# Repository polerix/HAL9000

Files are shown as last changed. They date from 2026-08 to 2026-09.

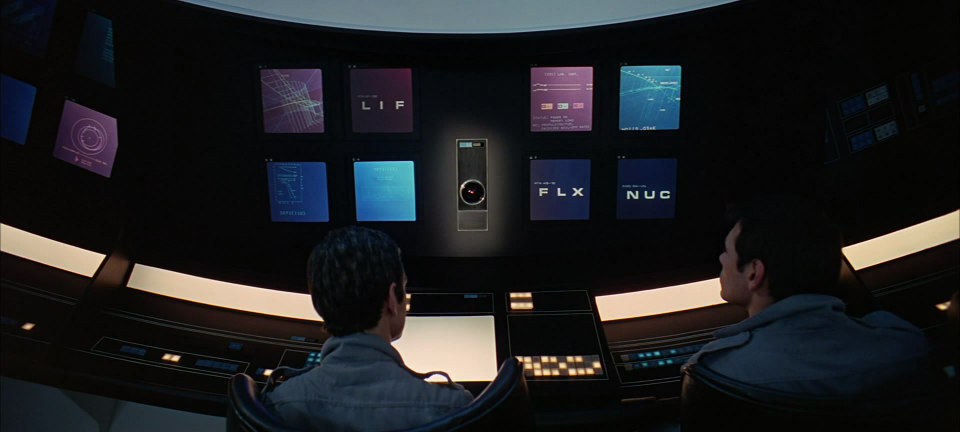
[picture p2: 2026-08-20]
Images/HAL9000_Resources/hal-2001.jpg

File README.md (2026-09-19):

# HAL 9000 Viewscreen

Life-size HAL 9000 replica display system. A Pygame kiosk app drives a 7" 1024×600 HDMI display in portrait orientation (600×1024), cycling through 12 spacecraft systems every 30 seconds and showing two panels per system:

- **High Screen** – Red function label panel with the active system code (e.g. `ATM`, `NAV`, `DMG`)
- **Lower Screen** – Looping video animation matching the current function

Primary deployment target is a Raspberry Pi 3 driving the physical prop display — see [`RaspberryPi 3.md`](RaspberryPi%203.md) for hardware wiring, HDMI/portrait config, and the systemd service. This README covers running and developing the app, including on a desktop (macOS/Linux) for testing.

## Requirements

- Python 3.10+
- [`pygame-ce`](https://pyga.me/) (community fork of pygame — see note below)

Dependencies are pinned in [`requirements.txt`](requirements.txt).

> **Why pygame-ce, not pygame:** `pygame` 2.6.1 has a circular-import bug in `pygame.font` on newer Python releases (confirmed on 3.14), which crashes the app on startup with `NotImplementedError: font module not available`. `pygame-ce` is an actively maintained, drop-in-compatible fork without that bug. If you're on an older/stable Python and prefer upstream `pygame`, it should still work — just swap the pin in `requirements.txt`.

## Quick Start (Desktop / macOS testing)

Use a virtual environment so nothing touches your system Python:

```bash
cd HAL9000
python3 -m venv .venv
source .venv/bin/activate
pip install -r requirements.txt

python3 hal_viewscreen.py --windowed   # windowed, for testing
python3 hal_viewscreen.py              # fullscreen
```

`.venv/` is self-ignored by git (venvs created with `python -m venv` write their own `.gitignore`), so it never needs to be committed.

## Quick Start (Raspberry Pi 3, production)

```bash
git clone <repo-url> ~/HAL9000
cd ~/HAL9000
chmod +x setup_pi.sh
sudo ./setup_pi.sh
sudo reboot
```

Full hardware setup, HDMI portrait config, and systemd service management: see [`RaspberryPi 3.md`](RaspberryPi%203.md).

## Keyboard Controls (Testing)

| Key | Action |
|---|---|
| `→` Right Arrow | Next function |
| `←` Left Arrow | Previous function |
| `Space` | Resume auto-cycling |
| `Esc` | Quit |

## System Functions

| Code | System | Subtitle |
|---|---|---|
| ATM | Spacecraft Atmosphere Monitoring | O2N: 14-RA |
| CNT | Control | SYS: 09-MX |
| COM | Communications | FRQ: 31-AE |
| DMG | System Damage | GPM: 72-KC |
| FLX | Flight Dynamics | DYN: 58-PL |
| GDE | Guidance Data Extension | NAV: 43-QR |
| HIB | Hibernation | CRY: 06-TB |
| LIF | Life Support | ENV: 21-SG |
| MEM | Memory | BNK: 88-FH |
| NAV | Navigation | TRJ: 55-WD |
| NUC | Nuclear Reactor Status | RCT: 37-JN |
| VEH | Vehicle Status | HUL: 64-BV |

## Architecture

```
hal_viewscreen.py      Main application (Pygame)
├── config.py          Constants, layout, function definitions
├── Video/             MP4 animations (7-8 per function)
├── Fonts/             Eurostile KFB font family
└── Artwork/SVG/       Screen layout + example panel
```

## Files

| File | Purpose |
|---|---|
| `hal_viewscreen.py` | Main display application |
| `config.py` | Configuration & constants |
| `requirements.txt` | Python dependencies |
| `setup_pi.sh` | Raspberry Pi setup script |
| `hal9000-viewscreen.service` | Systemd auto-start unit (Pi) |
| `RaspberryPi 3.md` | Hardware setup & Pi deployment reference |
| `7" ScreenSpecifications.md` | Display hardware spec sheet |

## Notes

- Video playback is fully in-window: frames are decoded with OpenCV and drawn directly onto the same pygame surface as the rest of the UI, rather than shelling out to an external player. There is no separate OS-level video window to position — the whole display is one window.
- This is software decoding. See [`RaspberryPi 3.md`](RaspberryPi%203.md) for a note on Pi 3 performance if you deploy there.
- The `set_function()` API in `FunctionController` is ready for external control (Arduino serial, network, etc.)
- Cycle interval is configurable in `config.py` (`CYCLE_INTERVAL_SEC`)
- Font rendering uses Eurostile KFB Bold Extended (matching the movie prop typography)

## Licensing

The source code in this repository is released under the [MIT License](LICENSE).

Third-party material bundled in this repository (fonts, audio, video, artwork, saved web pages and similar files) is **not** covered by that license. It remains the property of its respective owners and is included under their own terms. If you are a rights holder and want something removed, please open an issue.

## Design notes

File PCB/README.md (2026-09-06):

# HAL 9000 Keypad PCB

10-button backlit keypad for the HAL 9000 terminal. Connects to a Vasiumic MCP23017 I2C GPIO expander via Dupont wires.

## Specs
- Board: 75.10 × 30.20 mm, 2-layer
- Buttons: 6×6×5mm momentary tactile, 4-pin DIP, 15mm pitch (2×5 grid)
- LEDs: 5mm through-hole, always-on, one per button in function color
- Resistors: current-limiting per LED color (330Ω red, 270Ω green, 180Ω blue, 300Ω amber)
- J1: 10-pin 2.54mm Dupont → MCP23017 GPA0–7 + GPB0–1
- J2: 2-pin power (5V + GND)

## Button Layout (row × col)
| | Col 1 | Col 2 | Col 3 | Col 4 | Col 5 |
|---|---|---|---|---|---|
| Row 1 | HIB | LIF | COM | NAV | MEM |
| Row 2 | ATM | FLX | NUC | WEA | MED |

## Files
- `hal9000-keypad/` — KiCad project (.kicad_sch, .kicad_pcb, .kicad_pro)
- `hal9000-keypad-pcb.zip` — full project archive for peer review
- `author-hal9000-keypad.mjs` — MCP authoring script that generated this design

## Notes
Resistors may need manual placement adjustment in KiCad PCB editor to clear courtyard overlaps (all nets and footprints are correct).

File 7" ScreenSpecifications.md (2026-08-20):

Generic 7 Inch 
1024 * 600 
DIY Portable LCD Display Screen Monitor 
Mini-HDMI Driver Control Board PC Computer Secondary Screen
black 
7C GQ -852
PCB80052

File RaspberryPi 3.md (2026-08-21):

# HAL 9000 – Raspberry Pi 3 Viewscreen

## Overview

Life-size HAL 9000 replica display system running on Raspberry Pi 3. Drives a 7" 1024×600 HDMI display in portrait orientation (600×1024), showing two panels:

- **High Screen** – Red function label panel with the active system code (e.g. `ATM`, `NAV`, `DMG`)
- **Lower Screen** – Looping video animation matching the current function

The display cycles through 12 spacecraft systems every 30 seconds, randomly selecting one of 7-8 available animations per system.

## Hardware

| Component | Specification |
|---|---|
| Computer | Raspberry Pi 3 Model B |
| Display | Generic 7" 1024×600 HDMI (PCB80052, 7C GQ-852) |
| Connection | Mini-HDMI to HDMI |
| Orientation | Portrait (600×1024) |

## Quick Start

### 1. Clone to Raspberry Pi
```bash
git clone <repo-url> ~/HAL9000
cd ~/HAL9000
```

### 2. Run Setup
```bash
chmod +x setup_pi.sh
sudo ./setup_pi.sh
sudo reboot
```

### 3. Start Manually (for testing)
```bash
# Windowed mode (on desktop)
python3 hal_viewscreen.py --windowed

# Fullscreen
python3 hal_viewscreen.py
```

### 4. Service Commands
```bash
sudo systemctl start hal9000-viewscreen    # Start
sudo systemctl stop hal9000-viewscreen     # Stop
sudo systemctl status hal9000-viewscreen   # Status
journalctl -u hal9000-viewscreen -f        # Live logs
```

## Keyboard Controls (Testing)

| Key | Action |
|---|---|
| `→` Right Arrow | Next function |
| `←` Left Arrow | Previous function |
| `Space` | Resume auto-cycling |
| `Esc` | Quit |

## System Functions

| Code | System | Subtitle | Panel Color |
|---|---|---|---|
| ATM | Spacecraft Atmosphere Monitoring | MRN: 80-EJ | Crimson Red (`#9D0032`) |
| CNT | Control | VER: 80-KJ | Sage Green (`#426F49`) |
| COM | Communications | PMT: 26-07 | Plum Magenta (`#733863`) |
| DMG | System Damage | GPM: 72-KC | Bright Crimson (`#C10341`) |
| FLX | Flight Dynamics | ATA: 48-12 | Royal Blue (`#294194`) |
| GDE | Guidance Data Extension | LIF: 13-AG | Cerulean Blue (`#2C4DA1`) |
| HIB | Hibernation | STA: 35-05 | Dark Teal (`#074941`) |
| LIF | Life Support | ATA: 61-08 | Rose Magenta (`#9E214B`) |
| MEM | Memory | PMT: 49-XB | Slate Steel Blue (`#17395A`) |
| NAV | Navigation | RTE: 09-EF | Deep Violet (`#52316B`) |
| NUC | Nuclear Reactor Status | AQS: 64-VN | Midnight Navy (`#0F1738`) |
| VEH | Vehicle Status | LIN: 86-QW | Cobalt Blue (`#2C4DA1`) |

## Architecture

```
hal_viewscreen.py      Main application (Pygame)
├── config.py          Constants, layout, function definitions
├── Video/             MP4 animations (7-8 per function)
├── Fonts/             Eurostile KFB font family
└── Artwork/SVG/       Screen layout + example panel
```

### Display Layout (600×1024)

```
┌──────────────────────────┐  0
│          (black)          │
│   ┌──────────────────┐   │  28px
│   │                  │   │
│   │   HIGH SCREEN    │   │
│   │   (red panel)    │   │
│   │   Function Label │   │
│   │                  │   │
│   └──────────────────┘   │  501px
│          (black)          │
│   ┌──────────────────┐   │  523px
│   │                  │   │
│   │   LOWER SCREEN   │   │
│   │   (video area)   │   │
│   │   video playback │   │
│   │                  │   │
│   └──────────────────┘   │  996px
│          (black)          │
└──────────────────────────┘  1024
    64px              537px
```

## Files

| File | Purpose |
|---|---|
| `hal_viewscreen.py` | Main display application |
| `config.py` | Configuration & constants |
| `setup_pi.sh` | Raspberry Pi setup script |
| `hal9000-viewscreen.service` | Systemd auto-start unit |
| `requirements.txt` | Python dependencies |

## Notes

- Videos are 4K source files decoded via OpenCV and drawn directly onto the pygame surface (in-process, same window as the rest of the UI — no separate player window). Frames are resized down to 473×473px each draw call.
- This is software decoding, not hardware-accelerated. On a Pi 3 this may not sustain smooth playback of full 4K source files — if you see dropped frames or high CPU, pre-transcode the videos in `Video/` down to roughly panel resolution (e.g. `ffmpeg -i in.mp4 -vf scale=473:473 out.mp4`) so decode cost matches what's actually displayed.
- The `set_function()` API in `FunctionController` is ready for external control (Arduino serial, network, etc.)
- Cycle interval is configurable in `config.py` (`CYCLE_INTERVAL_SEC`)
- Font rendering uses Eurostile KFB Bold Extended (matching the movie prop typography)

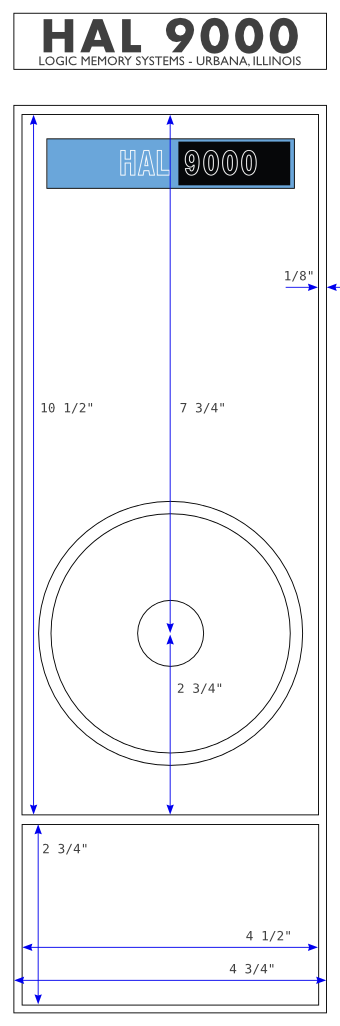
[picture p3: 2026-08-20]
Images/HAL9000_Resources/hal9000-faceplate.png

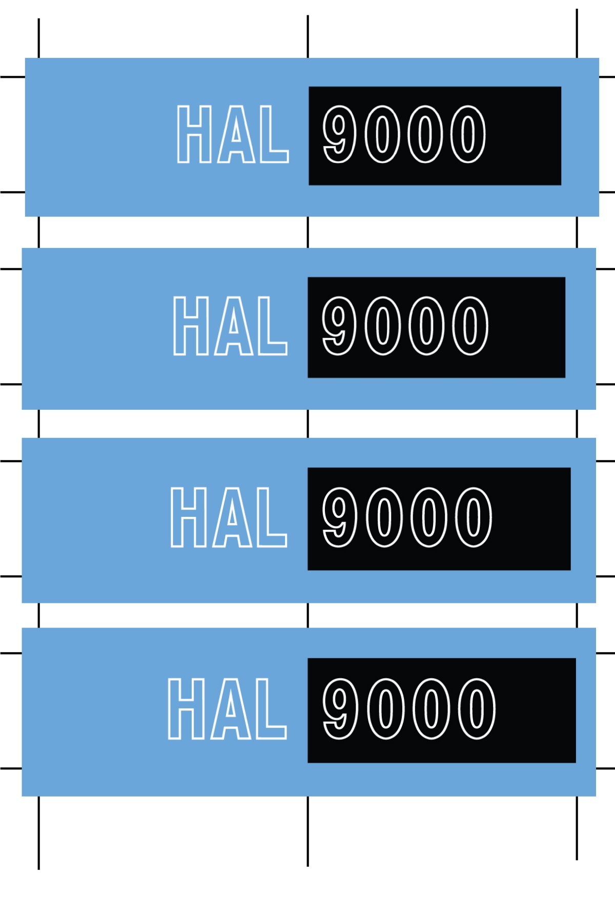
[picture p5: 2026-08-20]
Images/HAL9000_Resources/hal9000-decal.jpg

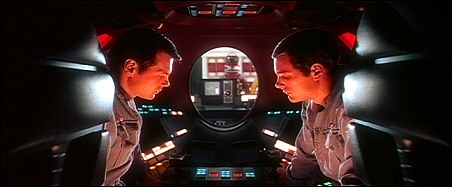
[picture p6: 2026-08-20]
Images/HAL9000_Resources/hal-podbay2.jpg

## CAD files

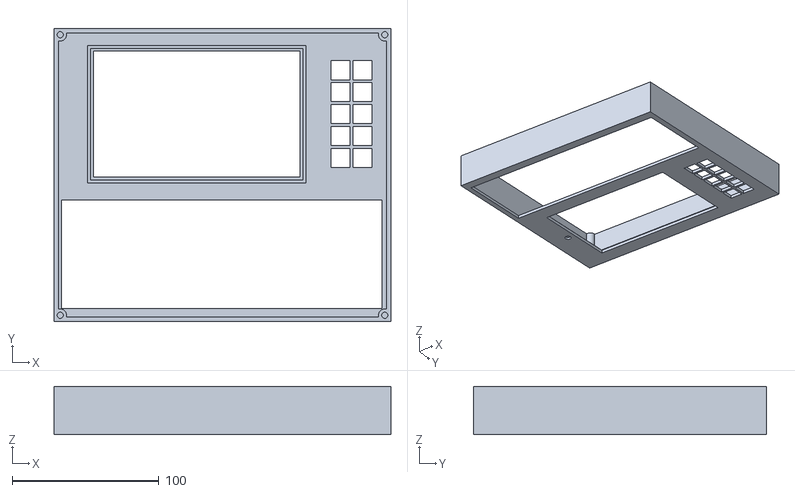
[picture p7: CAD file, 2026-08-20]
Terminal_Parts/Main Body.stl.stl
230.0 x 200.0 x 33.0

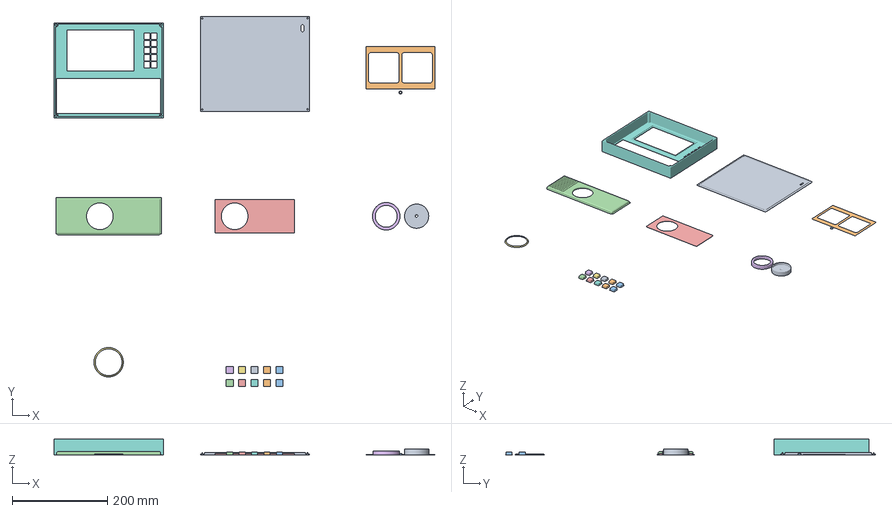
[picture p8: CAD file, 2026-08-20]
hal9000_Terminal.3mf
801.8 x 779.4 x 33.0 mm
Rear Cover.stl
Screen Border.stl
Faux Camera.stl
Silver Iris Panel.stl
Black Iris Panel.stl
Black Iris Border.stl
Silver Iris Ring.stl
Main Body.stl
Rear Lens Cap.stl
CLR Btn.stl
COMM Btn.stl
COMP Btn.stl
EXEC Btn.stl
HIB Btn.stl
LIF Btn.stl
PROG Btn.stl
STP Btn.stl
SYS Btn.stl
VOC Btn.stl

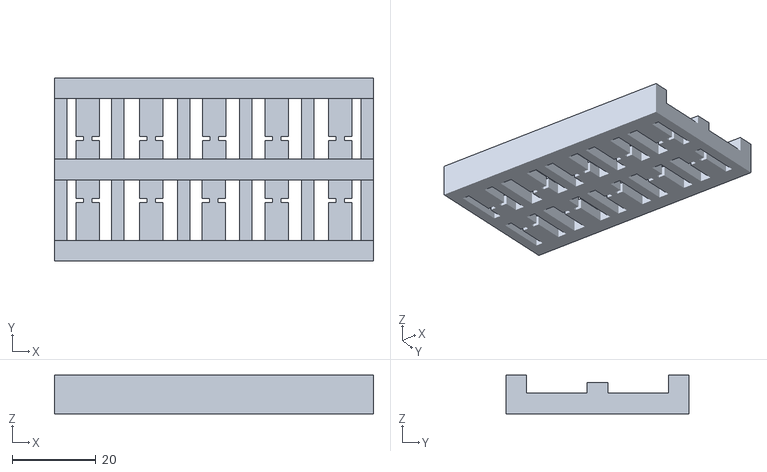
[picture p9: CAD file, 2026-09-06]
Terminal_Parts/Raspberry Pi HAL9000 screen Mask.stl
76.0 x 43.5 x 9.25

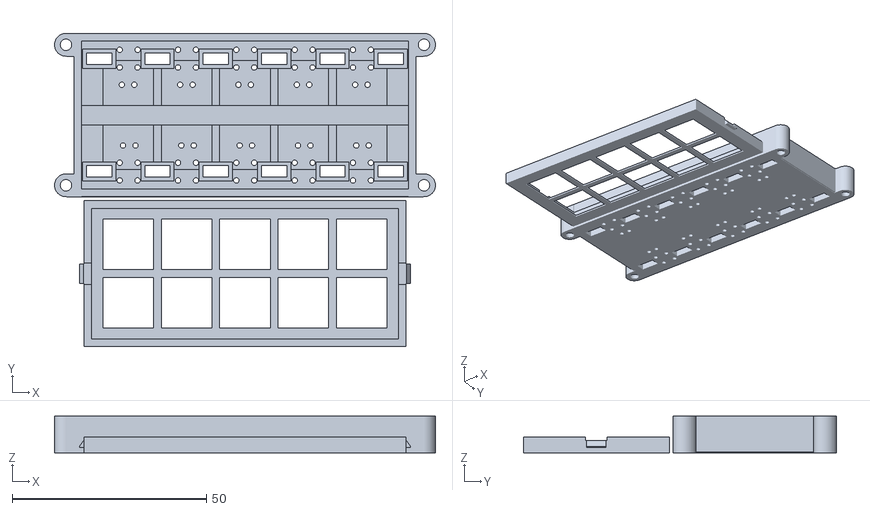
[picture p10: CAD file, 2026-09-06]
Terminal_Parts/Raspberry Pi HAL9000 keypad.stl
98.0 x 80.6 x 9.40

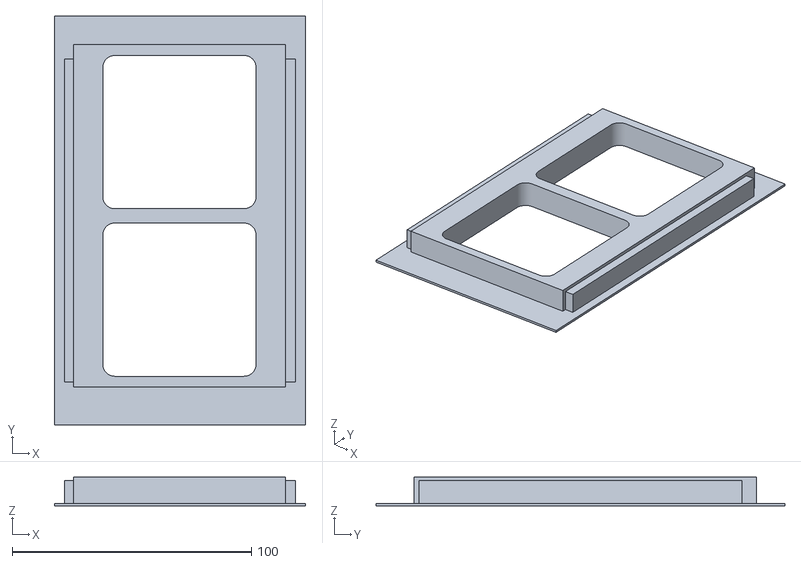
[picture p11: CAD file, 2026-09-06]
Terminal_Parts/Raspberry Pi HAL9000 screen blocker.stl
105.0 x 170.9 x 12.0

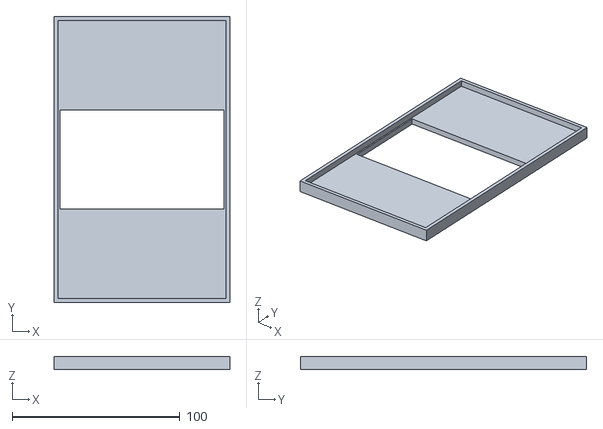
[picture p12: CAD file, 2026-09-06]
Terminal_Parts/Raspberry Pi HAL9000 screen cage.stl
105.0 x 170.9 x 8.00

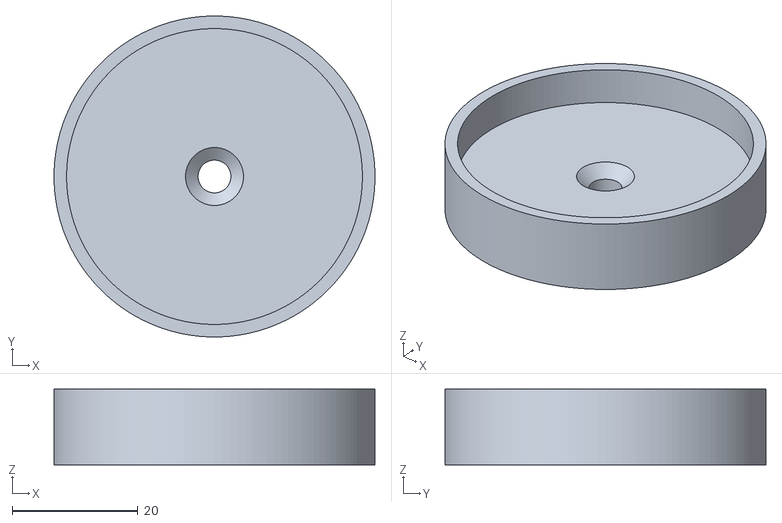
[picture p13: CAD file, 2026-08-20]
Terminal_Parts/Rear Lens Cap.stl.stl
51.0 x 51.0 x 12.0

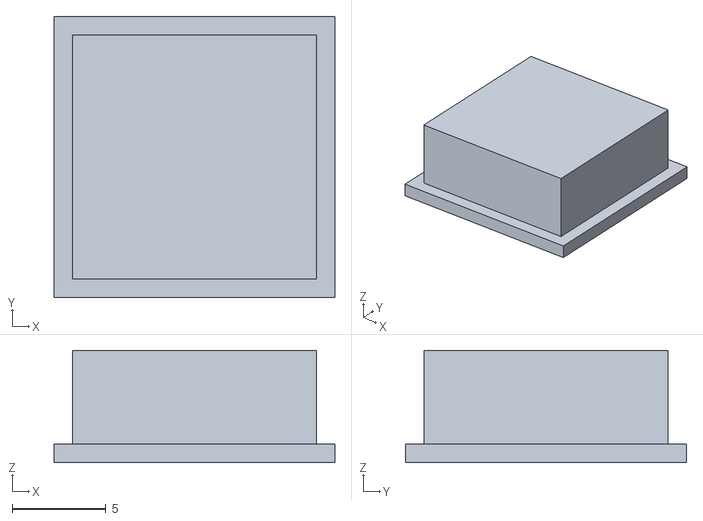
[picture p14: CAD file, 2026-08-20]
Terminal_Parts/SYS Btn.stl.stl
15.0 x 15.0 x 6.00

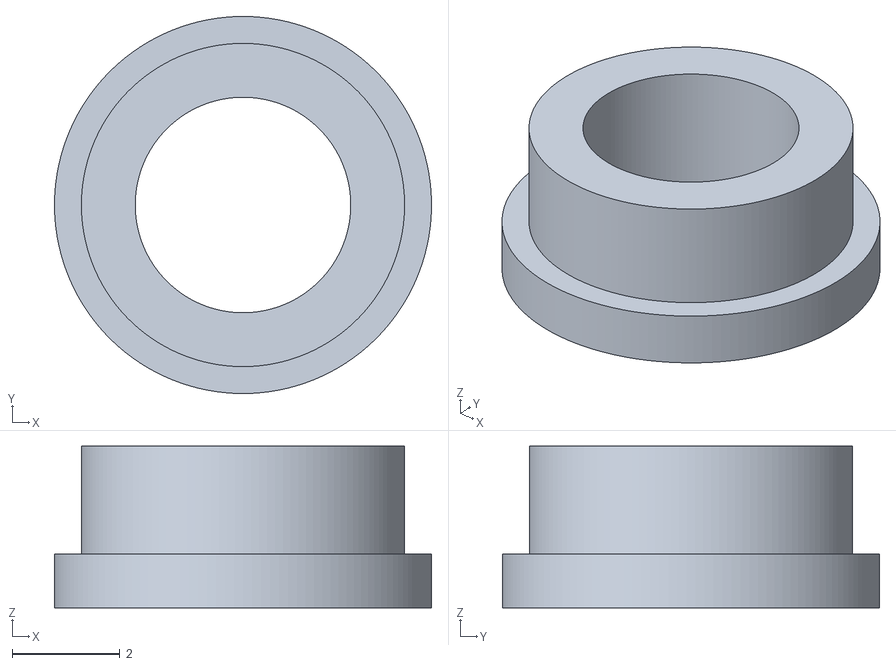
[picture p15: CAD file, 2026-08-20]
Terminal_Parts/Faux Camera.stl.stl
7.00 x 7.00 x 3.00

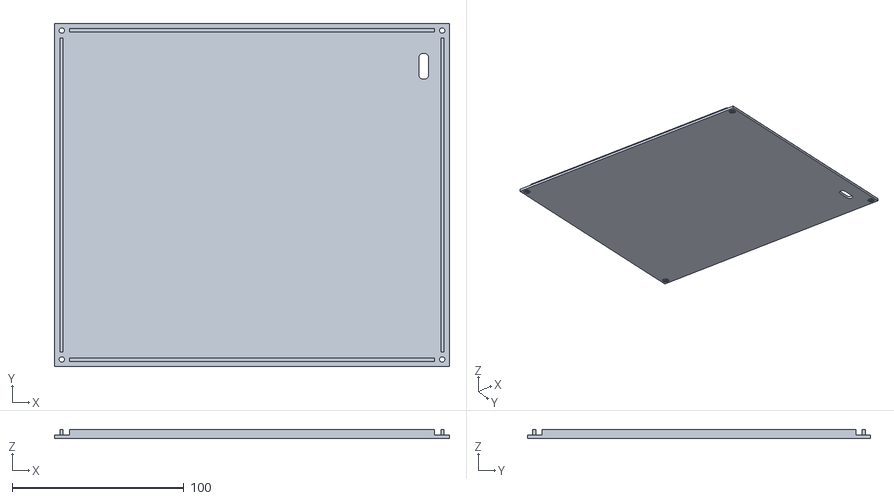
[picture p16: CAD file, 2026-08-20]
Terminal_Parts/Rear Cover.stl.stl
230.0 x 200.0 x 5.00

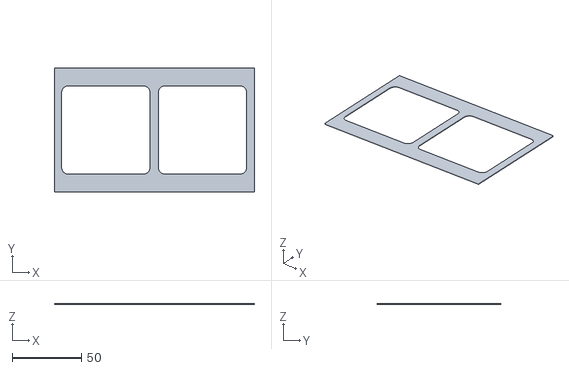
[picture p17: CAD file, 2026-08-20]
Terminal_Parts/Screen Border.stl.stl
144.8 x 89.8 x 1.00

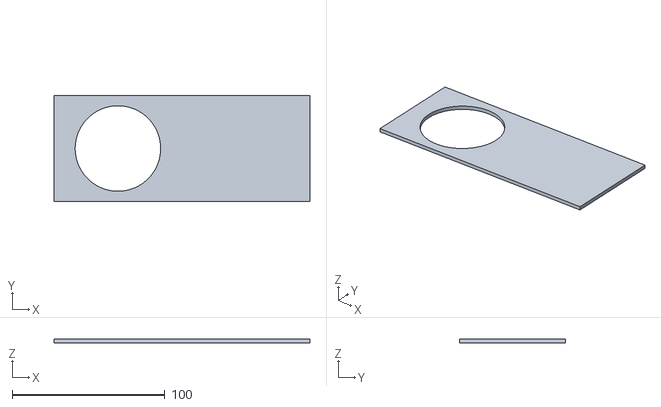
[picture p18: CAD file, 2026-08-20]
Terminal_Parts/Black Iris Panel.stl.stl
167.8 x 69.8 x 2.50

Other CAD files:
Terminal_Parts/PROG Btn.stl.stl
Terminal_Parts/HIB Btn.stl.stl
Terminal_Parts/EXEC Btn.stl.stl
Terminal_Parts/LIF Btn.stl.stl
Terminal_Parts/VOC Btn.stl.stl
Terminal_Parts/COMM Btn.stl.stl
Terminal_Parts/Black Iris Border.stl.stl
Terminal_Parts/CLR Btn.stl.stl
Terminal_Parts/COMP Btn.stl.stl
Terminal_Parts/STP Btn.stl.stl
Terminal_Parts/Silver Iris Panel.stl.stl
Terminal_Parts/Silver Iris Ring.stl.stl
Terminal_Parts/hal9000_Terminal.3mf

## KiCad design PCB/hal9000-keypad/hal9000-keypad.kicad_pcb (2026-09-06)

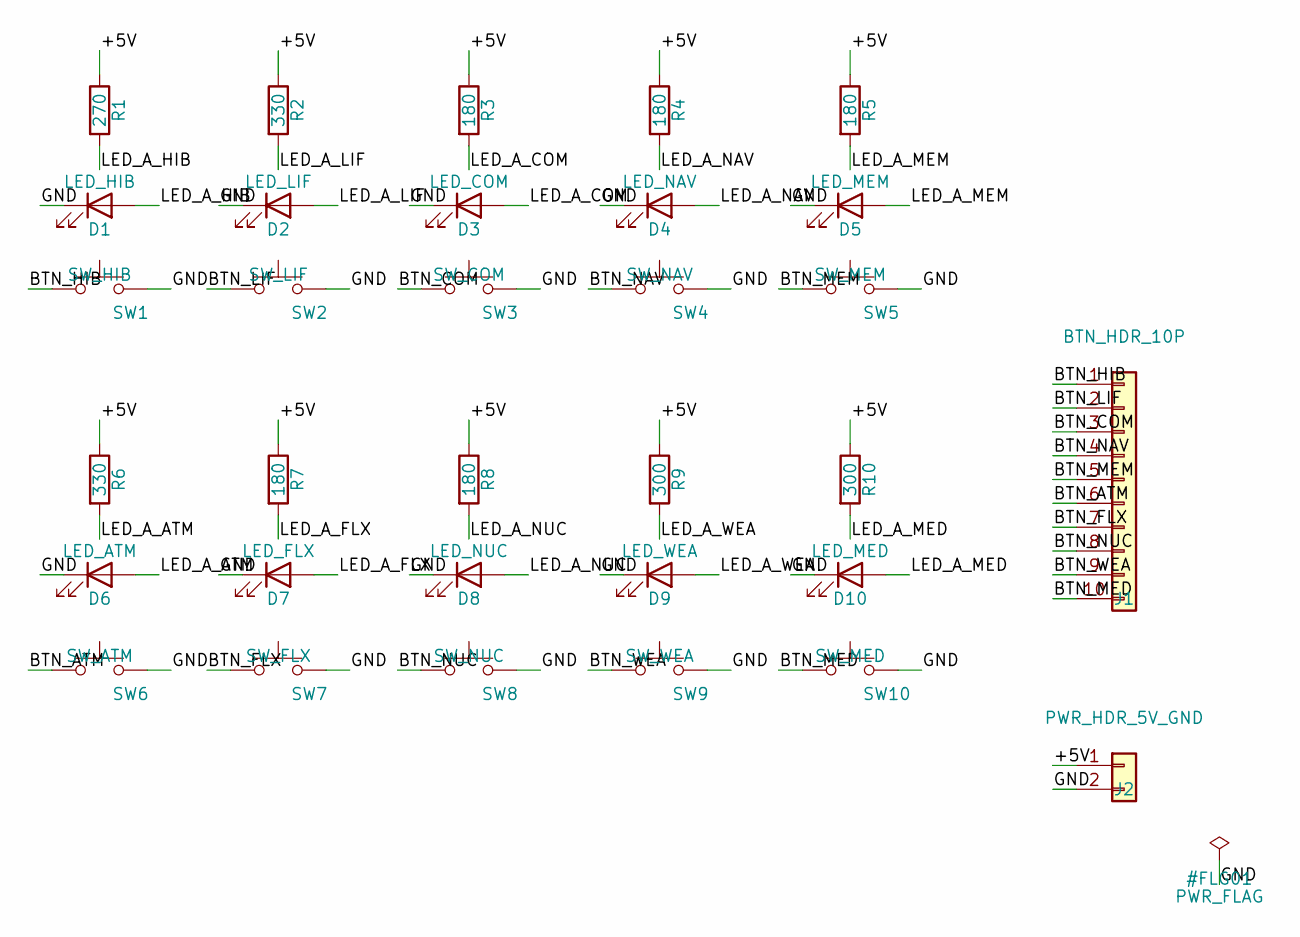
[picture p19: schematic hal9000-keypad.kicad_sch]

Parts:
D1: LED_HIB; LED_D5.0mm
D2: LED_LIF; LED_D5.0mm
D3: LED_COM; LED_D5.0mm
D4: LED_NAV; LED_D5.0mm
D5: LED_MEM; LED_D5.0mm
D6: LED_ATM; LED_D5.0mm
D7: LED_FLX; LED_D5.0mm
D8: LED_NUC; LED_D5.0mm
D9: LED_WEA; LED_D5.0mm
D10: LED_MED; LED_D5.0mm
J1: BTN_HDR_10P; PinHeader_1x10_P2.54mm_Vertical
J2: PWR_HDR_5V_GND; PinHeader_1x02_P2.54mm_Vertical
R1: 270; R_Axial_DIN0207_L6.3mm_D2.5mm_P10.16mm_Horizontal
R2, R6: 330; R_Axial_DIN0207_L6.3mm_D2.5mm_P10.16mm_Horizontal
R3, R4, R5, R7, R8: 180; R_Axial_DIN0207_L6.3mm_D2.5mm_P10.16mm_Horizontal
R9, R10: 300; R_Axial_DIN0207_L6.3mm_D2.5mm_P10.16mm_Horizontal
SW1: SW_HIB; SW_PUSH_6mm
SW2: SW_LIF; SW_PUSH_6mm
SW3: SW_COM; SW_PUSH_6mm
SW4: SW_NAV; SW_PUSH_6mm
SW5: SW_MEM; SW_PUSH_6mm
SW6: SW_ATM; SW_PUSH_6mm
SW7: SW_FLX; SW_PUSH_6mm
SW8: SW_NUC; SW_PUSH_6mm
SW9: SW_WEA; SW_PUSH_6mm
SW10: SW_MED; SW_PUSH_6mm

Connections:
+5V: J2.1, R1.1, R2.1, R3.1, R4.1, R5.1, R6.1, R7.1, R8.1, R9.1, R10.1
BTN_ATM: J1.6, SW6.1
BTN_COM: J1.3, SW3.1
BTN_FLX: J1.7, SW7.1
BTN_HIB: J1.1, SW1.1
BTN_LIF: J1.2, SW2.1
BTN_MED: J1.10, SW10.1
BTN_MEM: J1.5, SW5.1
BTN_NAV: J1.4, SW4.1
BTN_NUC: J1.8, SW8.1
BTN_WEA: J1.9, SW9.1
GND: D1.1 (K), D2.1 (K), D3.1 (K), D4.1 (K), D5.1 (K), D6.1 (K), D7.1 (K), D8.1 (K), D9.1 (K), D10.1 (K), J2.2, SW1.2, SW2.2, SW3.2, SW4.2, SW5.2, SW6.2, SW7.2, SW8.2, SW9.2, SW10.2
LED_A_ATM: D6.2 (A), R6.2
LED_A_COM: D3.2 (A), R3.2
LED_A_FLX: D7.2 (A), R7.2
LED_A_HIB: D1.2 (A), R1.2
LED_A_LIF: D2.2 (A), R2.2
LED_A_MED: D10.2 (A), R10.2
LED_A_MEM: D5.2 (A), R5.2
LED_A_NAV: D4.2 (A), R4.2
LED_A_NUC: D8.2 (A), R8.2
LED_A_WEA: D9.2 (A), R9.2

Board: 2 copper layers, 32 parts (0 on the bottom side), 22 nets, no tracks yet.

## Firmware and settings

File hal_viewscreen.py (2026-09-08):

#!/usr/bin/env python3
"""
HAL 9000 Viewscreen – Main Application
========================================
Fullscreen kiosk display for Raspberry Pi 3 with a 600×1024 HDMI screen.

Renders two panels:
  • High Screen – Function label (3-letter code + subtitle) on a red panel
  • Lower Screen – Looping video playback from the Video/ directory

Usage:
    python3 hal_viewscreen.py              # Run fullscreen
    python3 hal_viewscreen.py --windowed   # Run in a window (for testing)
"""

import os
import sys
import glob
import json
import random
import signal
import time
import argparse
import threading
import subprocess
import urllib.request as _urllib

import cv2
import pygame
import pygame.gfxdraw

from config import (
    SCREEN_WIDTH, SCREEN_HEIGHT,
    HIGH_SCREEN_X, HIGH_SCREEN_Y, PANEL_WIDTH, PANEL_HEIGHT, PANEL_CORNER_RADIUS,
    LOW_SCREEN_X, LOW_SCREEN_Y,
    COLOR_BLACK, COLOR_PANEL_RED, COLOR_TEXT_WHITE,
    FONT_BOLD_EXTENDED, FONT_EXTENDED, FONT_REGULAR,
    FONT_SIZE_CODE, FONT_SIZE_SUBTITLE,
    FUNCTIONS, FUNCTION_BY_CODE, VIDEO_DIR,
    CYCLE_INTERVAL_SEC, FPS,
    CACHE_WEA_PATH, CACHE_MED_PATH,
    ANTHROPIC_API_KEY,
    WEATHER_LAT, WEATHER_LON, WEATHER_CITY,
)


# ---------------------------------------------------------------------------
# Video Scanner
# ---------------------------------------------------------------------------

def scan_videos(video_dir: str) -> dict:
    """
    Scan the Video directory and map function codes to lists of video paths.

    Filenames follow the pattern:
        HAL 9000 Screensaver ... – ATM (Spacecraft ...) Animation N of M [...].mp4

    Returns:
        {"ATM": [path1, path2, ...], "CNT": [...], ...}
    """
    mapping = {}
    for func in FUNCTIONS:
        mapping[func["code"]] = []

    if not os.path.isdir(video_dir):
        print(f"[WARN] Video directory not found: {video_dir}")
        return mapping

    for filepath in sorted(glob.glob(os.path.join(video_dir, "*.mp4"))):
        basename = os.path.basename(filepath)
        # Extract function code from "– CODE (" pattern
        for func in FUNCTIONS:
            code = func["code"]
            # Match "– ATM " or "– ATM ("
            marker = f"– {code} ("
            if marker in basename:
                mapping[code].append(filepath)
                break

    for code, vids in mapping.items():
        print(f"[INFO] {code}: {len(vids)} video(s)")

    return mapping


# ---------------------------------------------------------------------------
# Rounded Rectangle Drawing
# ---------------------------------------------------------------------------

def draw_rounded_rect(surface, rect, color, radius=None):
    """
    Draw a filled rectangle with square corners.

    (Corners were previously rounded via pygame.gfxdraw circles, but the
    anti-aliased corner circles blended against the surface's existing
    pixels and left a faint dark outline. Square corners avoid that
    artifact entirely, so the rounding path was removed.)
    """
    pygame.draw.rect(surface, color, rect)


# ---------------------------------------------------------------------------
# High Screen Panel Renderer
# ---------------------------------------------------------------------------

class HighScreenPanel:
    """
    Renders the function label panel matching the example_panel.svg style:
    - Red (#c10341) rounded-rect background
    - Large white 3-letter function code (Eurostile KFB Bold Extended, 71px)
    - Smaller white subtitle (Eurostile KFB Extended, 17px)
    """

    def __init__(self):
        # Load fonts
        try:
            self.font_code = pygame.font.Font(FONT_BOLD_EXTENDED, FONT_SIZE_CODE)
            self.font_subtitle = pygame.font.Font(FONT_EXTENDED, FONT_SIZE_SUBTITLE)
            print(f"[INFO] Loaded Eurostile KFB fonts")
        except FileNotFoundError:
            print(f"[WARN] Eurostile KFB fonts not found, using system default")
            self.font_code = pygame.font.SysFont("monospace", FONT_SIZE_CODE, bold=True)
            self.font_subtitle = pygame.font.SysFont("monospace", FONT_SIZE_SUBTITLE)

        # Pre-render one colored background per function (color sourced from
        # Function.json via config.FUNCTION_BY_CODE), so each system gets
        # its own panel color instead of a single fixed red.
        self._bg_surfaces = {}
        for code, func in FUNCTION_BY_CODE.items():
            surface = pygame.Surface((PANEL_WIDTH, PANEL_HEIGHT), pygame.SRCALPHA)
            draw_rounded_rect(surface, (0, 0, PANEL_WIDTH, PANEL_HEIGHT),
                              func.get("color", COLOR_PANEL_RED), PANEL_CORNER_RADIUS)
            self._bg_surfaces[code] = surface

        self._default_bg = pygame.Surface((PANEL_WIDTH, PANEL_HEIGHT), pygame.SRCALPHA)
        draw_rounded_rect(self._default_bg, (0, 0, PANEL_WIDTH, PANEL_HEIGHT),
                          COLOR_PANEL_RED, PANEL_CORNER_RADIUS)

        self._current_code = None
        self._current_subtitle = None
        self._panel_surface = None

    def set_function(self, code: str, subtitle: str):
        """Update the displayed function."""
        if code == self._current_code and subtitle == self._current_subtitle:
            return  # No change

        self._current_code = code
        self._current_subtitle = subtitle

        func = FUNCTION_BY_CODE.get(code, {})
        text_color = func.get("text_color", COLOR_TEXT_WHITE)

        # Compose panel surface
        self._panel_surface = self._bg_surfaces.get(code, self._default_bg).copy()

        # Render the 3-letter code – centered, slightly below vertical center
        # (matching SVG: text at y=267.83 out of 472.5 → ~56.6% down)
        code_surface = self.font_code.render(code, True, text_color)
        code_x = (PANEL_WIDTH - code_surface.get_width()) // 2
        code_y = int(PANEL_HEIGHT * 0.45) - code_surface.get_height() // 2
        self._panel_surface.blit(code_surface, (code_x, code_y))

        # Render subtitle – centered, above the code
        # (matching SVG: text at y=189.92 out of 472.5 → ~40.2% down)
        sub_surface = self.font_subtitle.render(subtitle, True, text_color)
        sub_x = (PANEL_WIDTH - sub_surface.get_width()) // 2
        sub_y = int(PANEL_HEIGHT * 0.34) - sub_surface.get_height() // 2
        self._panel_surface.blit(sub_surface, (sub_x, sub_y))

    def draw(self, screen):
        """Blit the panel onto the main screen."""
        if self._panel_surface:
            screen.blit(self._panel_surface, (HIGH_SCREEN_X, HIGH_SCREEN_Y))


# ---------------------------------------------------------------------------
# Lower Screen Video Player
# ---------------------------------------------------------------------------

class VideoPlayer:
    """
    Decodes video frames (via OpenCV) and draws them directly onto the
    lower screen panel of the main pygame surface.

    This renders in-process rather than shelling out to an external
    player, so playback is always part of the same window as the rest
    of the UI — there is no separate OS-level player window to
    position, and no window chrome (title bar, rounded corners,
    dragging) to fight with.
    """

    def __init__(self):
        self._cap = None
        self._current_path = None
        self._frame_interval = 1.0 / 30.0
        self._next_frame_at = 0.0
        self._surface = None

    def play(self, video_path: str):
        """Start playing a video file. Stops any current playback first."""
        if video_path == self._current_path and self._cap is not None:
            return  # Already playing this video

        self.stop()

        if not os.path.isfile(video_path):
            print(f"[WARN] Video file not found: {video_path}")
            return

        cap = cv2.VideoCapture(video_path)
        if not cap.isOpened():
            print(f"[WARN] Failed to open video: {video_path}")
            cap.release()
            return

        self._cap = cap
        self._current_path = video_path
        fps = cap.get(cv2.CAP_PROP_FPS) or 30.0
        self._frame_interval = 1.0 / fps
        self._next_frame_at = 0.0
        self._surface = None
        print(f"[INFO] Playing: {os.path.basename(video_path)}")

    def stop(self):
        """Release the current video."""
        if self._cap is not None:
            self._cap.release()
        self._cap = None
        self._current_path = None
        self._surface = None

    def update(self):
        """
        Advance playback if enough real time has passed for the next
        frame, looping back to the start on end-of-stream. Call once
        per app frame before draw().
        """
        if self._cap is None:
            return

        now = time.monotonic()
        if self._surface is not None and now < self._next_frame_at:
            return  # Not time for the next frame yet

        ok, frame = self._cap.read()
        if not ok:
            self._cap.set(cv2.CAP_PROP_POS_FRAMES, 0)
            ok, frame = self._cap.read()
            if not ok:
                return  # Corrupt/empty video; keep showing last good frame

        frame = cv2.resize(frame, (PANEL_WIDTH, PANEL_HEIGHT), interpolation=cv2.INTER_AREA)
        frame = cv2.cvtColor(frame, cv2.COLOR_BGR2RGB)
        self._surface = pygame.image.frombuffer(
            frame.tobytes(), (PANEL_WIDTH, PANEL_HEIGHT), "RGB"
        )
        self._next_frame_at = now + self._frame_interval

    def draw(self, screen):
        """Draw the current video frame, or a black placeholder if none."""
        if self._surface is not None:
            screen.blit(self._surface, (LOW_SCREEN_X, LOW_SCREEN_Y))
        else:
            draw_rounded_rect(
                screen,
                (LOW_SCREEN_X, LOW_SCREEN_Y, PANEL_WIDTH, PANEL_HEIGHT),
                COLOR_BLACK,
                PANEL_CORNER_RADIUS,
            )


# ---------------------------------------------------------------------------
# Live Data Panel (WEA / MED)
# ---------------------------------------------------------------------------

# Codes that render live instead of playing a video
LIVE_CODES = {"WEA", "MED"}


class LiveDataPanel:
    """Renders WEA or MED live data into the low screen rect."""

    def __init__(self):
        try:
            self.font_lg = pygame.font.Font(FONT_BOLD_EXTENDED, 36)
            self.font_md = pygame.font.Font(FONT_EXTENDED, 22)
            self.font_sm = pygame.font.Font(FONT_REGULAR, 16)
        except FileNotFoundError:
            self.font_lg = pygame.font.SysFont("monospace", 36, bold=True)
            self.font_md = pygame.font.SysFont("monospace", 22)
            self.font_sm = pygame.font.SysFont("monospace", 16)
        self._wea_cache = None
        self._med_cache = None
        self._last_load = 0

    def _load_cache(self):
        now = time.time()
        if now - self._last_load < 30:
            return
        self._last_load = now
        try:
            with open(CACHE_WEA_PATH) as f:
                self._wea_cache = json.load(f)
        except Exception:
            self._wea_cache = None
        try:
            with open(CACHE_MED_PATH) as f:
                self._med_cache = json.load(f)
        except Exception:
            self._med_cache = None

    def _text(self, surface, text, font, color, x, y, max_width=440):
        """Render text with word-wrap. Returns next y position."""
        words = text.split()
        line = ""
        cy = y
        for word in words:
            test = line + (" " if line else "") + word
            if font.size(test)[0] > max_width and line:
                surf = font.render(line, True, color)
                surface.blit(surf, (x, cy))
                cy += surf.get_height() + 2
                line = word
            else:
                line = test
        if line:
            surf = font.render(line, True, color)
            surface.blit(surf, (x, cy))
            cy += surf.get_height() + 2
        return cy

    def render_wea(self, surface, rect):
        self._load_cache()
        rx, ry, rw, rh = rect
        pad = 16
        cx = rx + pad
        cy = ry + pad
        WHITE = (241, 241, 241)
        AMBER = (212, 160, 23)
        GREY  = (160, 160, 160)

        pygame.draw.rect(surface, (10, 10, 10), rect)
        if not self._wea_cache:
            self._text(surface, "AWAITING TELEMETRY", self.font_md, AMBER, cx, ry + 200)
            return

        w = self._wea_cache
        cy = self._text(surface, w.get("city", "").upper(), self.font_lg, WHITE, cx, cy)
        cy += 8

        temp_str = f"{w['temp']}°C"
        surf = self.font_lg.render(temp_str, True, AMBER)
        surface.blit(surf, (cx, cy))
        cy += surf.get_height() + 4

        cy = self._text(surface, w.get("condition", ""), self.font_md, WHITE, cx, cy)
        cy += 6

        rows = [
            ("FEELS LIKE", f"{w.get('feels_like', '—')}°C"),
            ("WIND",       f"{w.get('wind_kmh', '—')} km/h"),
            ("RAIN",       f"{w.get('rain_mm', 0)} mm"),
            ("SNOW",       f"{w.get('snow_cm', 0)} cm"),
        ]
        for label, val in rows:
            lsurf = self.font_sm.render(label, True, GREY)
            vsurf = self.font_md.render(val, True, WHITE)
            surface.blit(lsurf, (cx, cy + 4))
            surface.blit(vsurf, (cx + 160, cy))
            cy += vsurf.get_height() + 8

        ts = self.font_sm.render(f"UPD {w.get('fetched_at', '')}", True, GREY)
        surface.blit(ts, (cx, ry + rh - 28))

    def render_med(self, surface, rect):
        self._load_cache()
        rx, ry, rw, rh = rect
        pad = 16
        cx = rx + pad
        cy = ry + pad
        WHITE = (241, 241, 241)
        AMBER = (212, 160, 23)
        GREY  = (160, 160, 160)

        pygame.draw.rect(surface, (10, 10, 10), rect)
        if not self._med_cache:
            self._text(surface, "AWAITING TELEMETRY", self.font_md, AMBER, cx, ry + 200)
            return

        m = self._med_cache
        cy = self._text(surface, "TRENDING", self.font_md, AMBER, cx, cy)
        cy += 4
        for item in (m.get("youtube") or [])[:2]:
            cy = self._text(surface, item.get("title", ""), self.font_sm, WHITE, cx, cy)
            cy += 4
        cy += 8

        div = self.font_sm.render("─" * 38, True, (60, 60, 60))
        surface.blit(div, (cx, cy)); cy += 18
        cy = self._text(surface, "WORLD NEWS", self.font_md, AMBER, cx, cy)
        cy += 4
        for item in (m.get("news") or [])[:4]:
            cy = self._text(surface, item.get("title", ""), self.font_sm, WHITE, cx, cy, max_width=440)
            cy += 3

        ts = self.font_sm.render(f"UPD {m.get('fetched_at', '')}", True, GREY)
        surface.blit(ts, (cx, ry + rh - 28))

    def render(self, surface, rect, code):
        if code == "WEA":
            self.render_wea(surface, rect)
        elif code == "MED":
            self.render_med(surface, rect)


# ---------------------------------------------------------------------------
# Function Controller
# ---------------------------------------------------------------------------

class FunctionController:
    """
    Manages which HAL function is currently active and handles cycling.
    Provides set_function() for external control (Arduino, network, etc).
    """

    def __init__(self, video_map: dict):
        self._video_map = video_map
        self._functions = FUNCTIONS
        self._current_index = 0
        self._last_change = 0.0
        self._manual_override = False

    @property
    def current(self) -> dict:
        return self._functions[self._current_index]

    def set_function(self, code: str):
        """
        Set a specific function by code. Used for external control.
        Disables auto-cycling until reset.
        """
        for i, func in enumerate(self._functions):
            if func["code"] == code:
                self._current_index = i
                self._last_change = time.time()
                self._manual_override = True
                return True
        return False

    def reset_auto_cycle(self):
        """Re-enable automatic cycling."""
        self._manual_override = False
        self._last_change = time.time()

    def update(self) -> bool:
        """
        Check if it's time to cycle to the next function.
        Returns True if the function changed.
        """
        if self._manual_override:
            return False

        now = time.time()
        if now - self._last_change >= CYCLE_INTERVAL_SEC:
            self._current_index = (self._current_index + 1) % len(self._functions)
            self._last_change = now
            return True
        return False

    def get_random_video(self) -> str:
        """Get a random video path for the current function, or None."""
        code = self.current["code"]
        videos = self._video_map.get(code, [])
        if videos:
            return random.choice(videos)
        return None


# ---------------------------------------------------------------------------
# Button Layout — MCP23017 I/O map (2×5 grid, active-low with pull-ups)
# GPA0-7 = HIB LIF COM NAV MEM ATM FLX NUC
# GPB0-1 = VOX STP
# ---------------------------------------------------------------------------
BUTTON_MAP = {
    0x0001: 'HIB', 0x0002: 'LIF', 0x0004: 'COM', 0x0008: 'NAV',
    0x0010: 'MEM', 0x0020: 'ATM', 0x0040: 'FLX', 0x0080: 'NUC',
    0x0100: 'VOX', 0x0200: 'STP',
}

# Keyboard fallback mapping (for windowed testing)
KEY_MAP = {
    pygame.K_F1: 'HIB', pygame.K_F2: 'LIF', pygame.K_F3: 'COM',
    pygame.K_F4: 'NAV', pygame.K_F5: 'MEM', pygame.K_F6: 'ATM',
    pygame.K_F7: 'FLX', pygame.K_F8: 'NUC',
    pygame.K_v:  'VOX', pygame.K_s:  'STP',
}


class ButtonPoller:
    """
    Polls the MCP23017 GPIO expander for button presses (active-low).
    Falls back gracefully if smbus2 is not available or the chip is absent.
    """
    MCP_ADDR = 0x20
    IODIRA, IODIRB = 0x00, 0x01
    GPPUA,  GPPUB  = 0x0C, 0x0D
    GPIOA,  GPIOB  = 0x12, 0x13

    def __init__(self):
        self._bus = None
        self._prev = 0xFFFF  # all released (active-low, pull-ups = 0xFFFF)
        try:
            import smbus2
            bus = smbus2.SMBus(1)
            bus.write_byte_data(self.MCP_ADDR, self.IODIRA, 0xFF)
            bus.write_byte_data(self.MCP_ADDR, self.IODIRB, 0xFF)
            bus.write_byte_data(self.MCP_ADDR, self.GPPUA,  0xFF)
            bus.write_byte_data(self.MCP_ADDR, self.GPPUB,  0xFF)
            self._bus = bus
            print("[INFO] MCP23017 button poller ready on I2C-1 @ 0x20")
        except Exception as e:
            print(f"[WARN] MCP23017 unavailable ({e}) — use F1-F8/V/S keys")

    def poll(self) -> list:
        """Return list of button codes newly pressed since last call."""
        if not self._bus:
            return []
        pressed = []
        try:
            a = self._bus.read_byte_data(self.MCP_ADDR, self.GPIOA)
            b = self._bus.read_byte_data(self.MCP_ADDR, self.GPIOB)
            # Active-low: invert so 1 = pressed
            state = ((b << 8) | a) ^ 0xFFFF
            newly = state & ~self._prev
            self._prev = state
            for mask, code in BUTTON_MAP.items():
                if newly & mask:
                    pressed.append(code)
        except Exception:
            pass
        return pressed

    def close(self):
        if self._bus:
            try: self._bus.close()
            except Exception: pass
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

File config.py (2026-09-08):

"""
HAL 9000 Viewscreen – Configuration
=====================================
Layout constants extracted from 600x1024_VideoScreen_Layout_bleed.svg
and example_panel.svg. All coordinates are in pixels for 600x1024 portrait display.
"""

import json
import os

# ---------------------------------------------------------------------------
# Paths
# ---------------------------------------------------------------------------
BASE_DIR = os.path.dirname(os.path.abspath(__file__))
ANIMATIONS_DIR = os.path.join(BASE_DIR, "Animations")
VIDEO_DIR = ANIMATIONS_DIR if os.path.isdir(ANIMATIONS_DIR) else os.path.join(BASE_DIR, "Video")
FONT_DIR = os.path.join(
    BASE_DIR, "Fonts", "Eurostile-Font-main",
    "Eurostile KFB (Self-created)"
)
FUNCTION_DATA_PATH = os.path.join(BASE_DIR, "Function.json")

# Eurostile KFB font files (matching the example_panel.svg styles)
FONT_BOLD_EXTENDED = os.path.join(FONT_DIR, "Eurostile KFB Bold Extended.ttf")
FONT_EXTENDED = os.path.join(FONT_DIR, "Eurostile KFB Extended.ttf")
FONT_REGULAR = os.path.join(FONT_DIR, "Eurostile KFB.ttf")

# ---------------------------------------------------------------------------
# Screen Dimensions
# ---------------------------------------------------------------------------
SCREEN_WIDTH = 600
SCREEN_HEIGHT = 1024

# ---------------------------------------------------------------------------
# Panel Geometry (extracted from SVG path data)
# ---------------------------------------------------------------------------
# Both panels are 472.6 x 472.6 rounded rects with 43.83px corner radius,
# horizontally centered in the 600px canvas.

PANEL_WIDTH = 473
PANEL_HEIGHT = 473
PANEL_CORNER_RADIUS = 44

# High screen (function label panel)
HIGH_SCREEN_X = 64       # (600 - 473) / 2 ≈ 63.7
HIGH_SCREEN_Y = 28       # from SVG: y starts at 28.19
HIGH_SCREEN_RECT = (HIGH_SCREEN_X, HIGH_SCREEN_Y, PANEL_WIDTH, PANEL_HEIGHT)

# Low screen (video playback area)
LOW_SCREEN_X = 64
LOW_SCREEN_Y = 523       # from SVG: y starts at 523.22
LOW_SCREEN_RECT = (LOW_SCREEN_X, LOW_SCREEN_Y, PANEL_WIDTH, PANEL_HEIGHT)

# ---------------------------------------------------------------------------
# Colors (from example_panel.svg)
# ---------------------------------------------------------------------------
COLOR_BLACK = (0, 0, 0)
COLOR_PANEL_RED = (193, 3, 65)          # #c10341 – red panel background
COLOR_TEXT_WHITE = (241, 241, 241)      # #f1f1f1 – panel text
COLOR_PANEL_BLUE = (38, 60, 197)        # #263cc5 – SVG cutout reference

# ---------------------------------------------------------------------------
# Typography (sizes from example_panel.svg, scaled to panel)
# The example SVG is 472.5x472.5; our panel is 473x473 — near 1:1 mapping.
# ---------------------------------------------------------------------------
FONT_SIZE_CODE = 71           # Large 3-letter function code (71.07px in SVG)
FONT_SIZE_SUBTITLE = 17       # Subtitle text (16.72px in SVG)

# ---------------------------------------------------------------------------
# Function Definitions
# ---------------------------------------------------------------------------
# Each function has: code, full name, subtitle (HAL-authentic identifier),
# and its own high-screen panel color. Loaded from Function.json, which is
# the source of truth for this data (colors curated per-system: reds for
# damage/life-critical systems, blues for navigation/reactor, etc).
# Subtitles follow the example_panel.svg pattern: "GPM: 72-KC"

# Fallback used only if Function.json is missing/malformed, so the app can
# still start. Matches the original static design (every panel red).
_FALLBACK_FUNCTIONS = [
    {"code": "ATM", "name": "Spacecraft Atmosphere Monitoring", "subtitle": "MRN: 80-EJ"},
    {"code": "CNT", "name": "Control",                         "subtitle": "VER: 80-KJ"},
    {"code": "COM", "name": "Communications",                  "subtitle": "PMT: 26-07"},
    {"code": "DMG", "name": "System Damage",                   "subtitle": "GPM: 72-KC"},
    {"code": "FLX", "name": "Flight Dynamics",                 "subtitle": "ATA: 48-12"},
    {"code": "GDE", "name": "Guidance Data Extension",         "subtitle": "LIF: 13-AG"},
    {"code": "HIB", "name": "Hibernation",                     "subtitle": "STA: 35-05"},
    {"code": "LIF", "name": "Life Support",                    "subtitle": "ATA: 61-08"},
    {"code": "MEM", "name": "Memory",                          "subtitle": "PMT: 49-XB"},
    {"code": "NAV", "name": "Navigation",                      "subtitle": "RTE: 09-EF"},
    {"code": "NUC", "name": "Nuclear Reactor Status",          "subtitle": "AQS: 64-VN"},
    {"code": "VEH", "name": "Vehicle Status",                  "subtitle": "LIN: 86-QW"},
]
for _f in _FALLBACK_FUNCTIONS:
    _f["color"] = COLOR_PANEL_RED
    _f["text_color"] = COLOR_TEXT_WHITE


def _hex_to_rgb(hex_str):
    hex_str = hex_str.lstrip("#")
    return tuple(int(hex_str[i:i + 2], 16) for i in (0, 2, 4))
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

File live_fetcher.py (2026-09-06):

#!/usr/bin/env python3
"""Background daemon: refreshes WEA and MED cache every FETCH_INTERVAL_SEC."""
import time, traceback
from config import FETCH_INTERVAL_SEC
import wea_fetcher, med_fetcher

def run():
    print("[live_fetcher] Starting")
    while True:
        for name, mod in [("WEA", wea_fetcher), ("MED", med_fetcher)]:
            try:
                mod.fetch()
                print(f"[live_fetcher] {name} updated")
            except Exception:
                print(f"[live_fetcher] {name} fetch failed:")
                traceback.print_exc()
        time.sleep(FETCH_INTERVAL_SEC)

if __name__ == "__main__":
    run()

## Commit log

2026-08-20 Initial commit: HAL 9000 Raspberry Pi 3 viewscreen implementation and resources
    [Black Iris Border.stl.stl, Black Iris Panel.stl.stl, CLR Btn.stl.stl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]
2026-08-20 Add README and pin pygame-ce in requirements.txt
    - requirements.txt: pygame-ce>=2.4.0 (drop-in fork of pygame; avoids
    a circular-import crash in pygame.font on newer Python releases)
    - README.md: top-level project overview covering desktop dev setup
    (venv + pygame-ce), quick start, keyboard controls, system
    function table, and file layout; links to RaspberryPi 3.md for
    hardware/Pi deployment details
    Claude-Session: https://claude.ai/code/session_01GrXkwWuGGPXr643fTAg7SU
2026-08-21 Embed video playback in the same window; drop mpv subprocess
    The lower screen was playing video via a separate mpv subprocess
    positioned to overlap the pygame window using absolute screen
    --geometry. On macOS this showed up as its own native, draggable,
    rounded-corner OS window rather than being part of the app — mpv's
    --wid embedding is unofficial/inconsistent on macOS (gpu-next ignores
    it outright; the legacy gpu/cocoa backend attached but didn't render
    reliably), so there's no supportable way to truly embed an external
    mpv window there.
    Replaced it with direct in-process frame rendering: VideoPlayer now
    decodes frames with OpenCV and blits them straight onto the same
    pygame surface as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
    [config.py, hal_viewscreen.py]
2026-08-21 Per-function high-screen panel colors from Function.json
    Each of the 12 HAL systems now renders its high-screen panel in its
    own curated color (and matching text color) instead of the single
    fixed red — e.g. DMG stays crimson, CNT is sage green, COM is plum
    magenta, NUC is midnight navy, etc.
    - config.py: FUNCTIONS is now loaded from Function.json (code, name,
    subtitle, color, text_color), with a hardcoded fallback list (all
    panels red/white, matching the prior static design) used if the
    file is missing or malformed so the app still starts. Adds
    FUNCTION_BY_CODE for lookup.
    - hal_viewscreen.py: HighScreenPanel pre-renders one background per
    function code from FUNCTION_BY_CODE an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
    [config.py, hal_viewscreen.py]
2026-09-06 Add LCARS landing page
2026-09-06 Add revised button SVGs and updated Function.json (10-button layout)
    [Raspberry Pi HAL9000 keypad.stl, Raspberry Pi HAL9000 screen Mask.stl, Raspberry Pi HAL9000 screen blocker.stl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]
2026-09-06 Add hal9000-keypad PCB project (schematic + board + authoring script)
    [hal9000-keypad.kicad_pcb, hal9000-keypad.kicad_sch]
2026-09-07 Add KiCad keypad project local config, footprint cache, and backup
2026-09-08 Add 1:1 prop-accurate HAL 9000 web terminal, 58mm circular eye with idle breathing, and web controls
2026-09-08 10-button layout + Claude Haiku VOX AI voice mode
    - SYSTEM_FUNCTIONS: 8 animation modes (HIB LIF COM NAV MEM ATM FLX NUC)
    - Buttons: HIB LIF COM NAV MEM / ATM FLX NUC VOX STP
    - New canvas renderers: MEM matrix, ATM pressure rings, FLX waveform, NUC core pulse
    - New low-screen telemetry: NUC heat map, MEM bus bars, ATM readout, FLX relay table
    - VOX: Web Speech Recognition -> Claude Haiku (HAL system prompt) -> speakHAL
    - STP: unified stop/abort for all active sequences
    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
2026-09-08 Add MCP23017 button polling, VoxController (Claude Haiku STT/TTS), setup overlay, weather integration
    - hal_viewscreen.py: ButtonPoller (MCP23017 via smbus2), VoxController (arecord→Google STT→Claude Haiku→espeak), _handle_button dispatcher, run() updated with button poll loop + keyboard fallback (F1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
    - HAL9000-TERMINAL-WEB.html: professional setup overlay (API key + weather city/country), SET button in HUD bar, Open-Meteo weather geocoding + 10-min refresh, callClaude() with weatherContext() inje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
    - config.py: ANTHROPIC_API_KEY env var, Moncton weather coords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
2026-09-08 Setup overlay: crew name field + voice selector with preview
    - Crew name input (default Dave) → crewName variable → injected into Claude system prompt
    - Voice dropdown populated from SpeechSynthesis.getVoices(), auto-selects male English voice
    - Preview button speaks a HAL sample line in selected voice at HAL rate/pitch
    - halVoice used by speakHAL (overrides old auto-pick logic)
    - initializeSetup captures crewName + halVoice on Initialize
2026-09-08 feat: VOX screen VU meter — live mic input on low-screen canvas
    When VOX is pressed, low-screen canvas switches to VOICE INPUT mode:
    - getUserMedia mic capture -> AnalyserNode (fftSize 64)
    - 16 VU bars, green->yellow->red by level
    - State label: LISTENING (green) / PROCESSING (amber)
    - Amber header/footer rules, Share Tech Mono typography
    - _startVoxScreen / _drawVoxScreen / _stopVoxScreen lifecycle
    - Restores normal canvas on STP, speech end, or error
2026-09-09 style: white HUD controls, stronger terminal amber rear-lighting
    - HUD bar border, header, button borders: gold -> white (matches
    manual control buttons)
    - Terminal box-shadow: three-layer amber glow (80px / 160px / 320px)
    so rear-lighting reads against pure black background
    - Body radial gradient: wider ellipse, higher opacity warm centre
    so the terminal bloom is visible
2026-09-19 chore: steward housekeeping (#4)
    * chore(steward): license-missing
    Claude-Session: https://claude.ai/code/session_01STMKJe7uSqfUXdrDZum4Qz
    * docs: add licensing notice (code is MIT; bundled third-party material is not covered)
    Claude-Session: https://claude.ai/code/session_01STMKJe7uSqfUXdrDZum4Qz
    ---------
